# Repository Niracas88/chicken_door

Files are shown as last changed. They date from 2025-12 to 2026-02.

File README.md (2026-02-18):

# LoRa Chicken Door – Arduino + ESP32 WROOM32D + Home Assistant

Dit project bestaat uit twee onderdelen:

1. **Arduino UNO + RFM95W (LoRa-zender/ontvanger)**
2. **ESP32 WROOM32D + RFM95W (LoRa-brug naar Home Assistant via ESPHome)**

Samen vormen ze een draadloze, betrouwbare oplossing om een kippenluik automatisch te openen/sluiten op basis van lichtsterkte, met statusrapportering, remote instellingen en diagnostiek.
https://app.cirkitdesigner.com/project/e5ca5108-8e1d-4cd1-b3eb-05e4a613478f

---

## 📡 Overzicht van de werking

### Arduino-zijde
- Stuurt een motor die het kippenluik opent/sluit.
- Leest sensoren:
  - LDR lichtsensor  
  - Bovenste en onderste reedcontacten  
- Bepaalt automatisch:
  - **OPEN / CLOSED / MOVING / ERROR**  
- Verzendt periodiek een **JSON-statuspakket** via LoRa:
```json
{
  "light": 512,
  "threshold": 600,
  "door": "OPEN",
  "reedTop": 0,
  "reedBottom": 1
}

###📡 LoRa-commando’s**
Verwerkt inkomende LoRa-commando’s:

'T' + value → stel nieuwe lichtdrempel in

'S' → zend status terug

### 🛰 ESP32 LoRa Bridge (ESPHome)
De ESP32 ontvangt LoRa-berichten van de Arduino en publiceert die als entiteiten in Home Assistant:

Lichtwaarde
Drempelwaarde
LoRa RSSI en SNR
Reed-statussen
Luikstatus
Timestamps van RX/TX

Via Home Assistant kun je:

De lichtdrempel instellen (0–255, LoRa-schaal)

Handmatig een statusrequest naar de Arduino sturen

De ESP32 gebruikt een aangepaste sx127x driver via:

external_components:
  - source: github://pr#7490
    components: [ sx127x ]

### 🔧 Hardwarepinnen
Arduino UNO → RFM95W
Signaal	Pin
NSS	7
RST	6
DIO0	3
MOSI	11
MISO	12
SCK	13
ESP32 WROOM32D → RFM95W
Signaal	GPIO
NSS	5
RST	14
DIO0	26
MOSI	23
MISO	19
SCK	18

### 🧱 Dependencies
Arduino
LoRa library
EEPROM (standaard)
SPI (standaard)
ESPHome
ESPHome 2025.10.0 of recenter
Externe sx127x component via PR
Home Assistant (optioneel maar aanbevolen)

### 🧪 Testen

Start de Arduino → zou LoRa gereed moeten melden.
Start de ESP32 → ESPHome-console moet RX-pakketten tonen.
In Home Assistant verschijnen automatisch:
lichtsensor
drempel
reed-statussen
luikstatus
Verander de drempel → ESP32 verstuurt 'T'-pakket → Arduino past waarde aan.

### 📁 Bestanden

/kippenluik_v4_LoRa_def.ino
/esp32-wroom32D-LoRa_def.yaml
/README.md (dit document)

### 📜 Licentie
Vrij te gebruiken en aan te passen voor niet-commerciële projecten.

###💬 Contact / Issues

Open een GitHub issue bij fouten, suggesties of vragen.
Laat het weten als je ook een **GitHub badge header**, **screenshots-sectie**, of een **diagram van de L

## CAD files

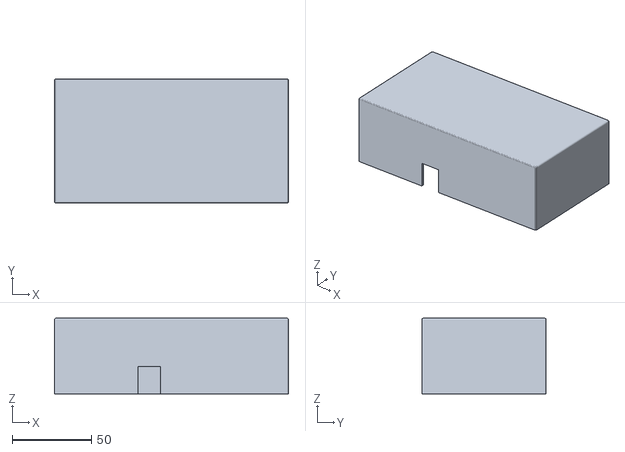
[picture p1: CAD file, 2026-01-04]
Arduino chicken coop box_lid.stl
147.4 x 78.4 x 47.7

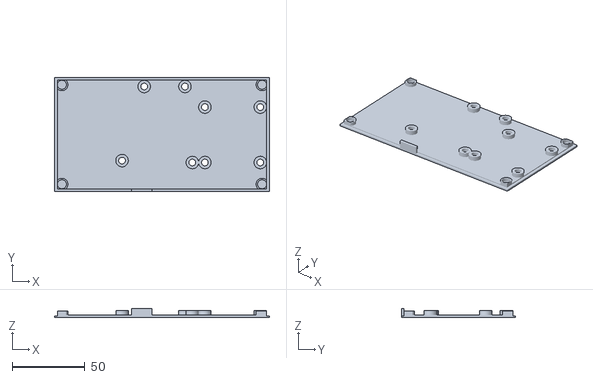
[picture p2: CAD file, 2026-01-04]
Arduino chicken coop box_bottom.stl
147.4 x 78.4 x 6.50

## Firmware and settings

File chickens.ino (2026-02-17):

#include <Arduino.h>
#include <EEPROM.h>

// ---------- Types (MOET bovenaan) ----------
typedef struct {
  bool top;
  bool bottom;
} Reeds;

// ---------- Forward declarations (veilig op Arduino IDE) ----------
bool reedRaw(int pin);
bool reedStable(int pin, unsigned long ms = 30);
Reeds readReeds();
void syncStateFromReeds(const Reeds& r);
void printStatus(int lightValue, const Reeds& r);
void handleSerial();
void calibrate();
bool moveTo(bool toOpen);
void updateLightMode(int lightValue);
bool motorActive = false;


// =====================================================
// MINIMALE, ROBUUSTE KIPPENLUIK-CODE (zonder LoRa)
// =====================================================

// -----------------------------
// Pinconfig
// -----------------------------
const int ENA = 10, IN1 = 9, IN2 = 8;
const int reedTop = 2, reedBottom = 4, LDRpin = A0;
const uint8_t PWM_SPEED = 200;

// -----------------------------
// EEPROM adressen
// -----------------------------
const int EEPROM_ADDR_THRESHOLD = 0;
const int EEPROM_ADDR_OPEN_MS   = 4;
const int EEPROM_ADDR_CLOSE_MS  = 8;

// -----------------------------
// Lichtdrempel
// -----------------------------
const int LIGHT_DEFAULT = 500;
int lightThreshold = LIGHT_DEFAULT;

// Hysterese + stabiliteit
const int LIGHT_HYST = 30;
const unsigned long LIGHT_STABLE_MS = 15000UL;

// -----------------------------
// Timeouts
// -----------------------------
const unsigned long DEFAULT_OPEN_MS  = 10000UL;
const unsigned long DEFAULT_CLOSE_MS = 10000UL;
const unsigned long MIN_TIMEOUT_MS   = 100000UL;
const unsigned long MAX_TIMEOUT_MS   = 100000UL;

const float         CAL_MARGIN_FACTOR = 1.25f;
const unsigned long CAL_MARGIN_MS     = 1000UL;

unsigned long maxOpenTime  = DEFAULT_OPEN_MS;
unsigned long maxCloseTime = DEFAULT_CLOSE_MS;

// -----------------------------
// State
// -----------------------------
enum DoorState { UNKNOWN, OPEN, CLOSED, MOVING_UP, MOVING_DOWN, ERROR_STATE };
DoorState state = UNKNOWN;

// -----------------------------
// Motor helpers
// -----------------------------
void motorStop() {
  analogWrite(ENA, 0);
  digitalWrite(IN1, LOW);
  digitalWrite(IN2, LOW);
  motorActive = false;

}
void motorUp() {
  analogWrite(ENA, PWM_SPEED);
  digitalWrite(IN1, HIGH);
  digitalWrite(IN2, LOW);
  motorActive = true;

}
void motorDown() {
  analogWrite(ENA, PWM_SPEED);
  digitalWrite(IN1, LOW);
  digitalWrite(IN2, HIGH);
  motorActive = true;

}

// -----------------------------
// Reed helpers
// -----------------------------
bool reedRaw(int pin) { return digitalRead(pin) == LOW; }

bool reedStable(int pin, unsigned long ms) {
  bool v = reedRaw(pin);
  unsigned long t0 = millis();
  while (millis() - t0 < ms) {
    bool v2 = reedRaw(pin);
    if (v2 != v) { v = v2; t0 = millis(); }
  }
  return v;
}

Reeds readReeds() {
  Reeds r;
  r.top = reedStable(reedTop, 30);
  r.bottom = reedStable(reedBottom, 30);
  return r;
}

// -----------------------------
// EEPROM load/save
// -----------------------------
unsigned long clampTimeout(unsigned long t) {
  if (t < MIN_TIMEOUT_MS) return MIN_TIMEOUT_MS;
  if (t > MAX_TIMEOUT_MS) return MAX_TIMEOUT_MS;
  return t;
}

void saveThreshold(int v) {
  v = constrain(v, 0, 1023);
  EEPROM.put(EEPROM_ADDR_THRESHOLD, v);
  lightThreshold = v;
  Serial.print("Threshold saved: "); Serial.println(lightThreshold);
}

void saveTimes(unsigned long openMs, unsigned long closeMs) {
  openMs = clampTimeout(openMs);
  closeMs = clampTimeout(closeMs);
  EEPROM.put(EEPROM_ADDR_OPEN_MS, openMs);
  EEPROM.put(EEPROM_ADDR_CLOSE_MS, closeMs);
  maxOpenTime = openMs;
  maxCloseTime = closeMs;
  Serial.print("Times saved: open="); Serial.print(maxOpenTime);
  Serial.print(" close="); Serial.println(maxCloseTime);
}

void loadConfig() {
  int thr;
  EEPROM.get(EEPROM_ADDR_THRESHOLD, thr);
  if (thr < 0 || thr > 1023) thr = LIGHT_DEFAULT;
  lightThreshold = thr;

  EEPROM.get(EEPROM_ADDR_OPEN_MS, maxOpenTime);
  EEPROM.get(EEPROM_ADDR_CLOSE_MS, maxCloseTime);

  if (maxOpenTime == 0 || maxOpenTime > 0xFFFFFFUL) maxOpenTime = DEFAULT_OPEN_MS;
  if (maxCloseTime == 0 || maxCloseTime > 0xFFFFFFUL) maxCloseTime = DEFAULT_CLOSE_MS;

  maxOpenTime = clampTimeout(maxOpenTime);
  maxCloseTime = clampTimeout(maxCloseTime);
}

// -----------------------------
// Status / state sync
// -----------------------------
const char* stateStr(DoorState s) {
  switch (s) {
    case OPEN: return "OPEN";
    case CLOSED: return "CLOSED";
    case MOVING_UP: return "MOVING_UP";
    case MOVING_DOWN: return "MOVING_DOWN";
    case ERROR_STATE: return "ERROR";
    default: return "UNKNOWN";
  }
}

void syncStateFromReeds(const Reeds& r) {
  if (r.top && !r.bottom) state = OPEN;
  else if (r.bottom && !r.top) state = CLOSED;
  else if (r.top && r.bottom) state = ERROR_STATE;
}

void printStatus(int lightValue, const Reeds& r) {
  Serial.print("Light="); Serial.print(lightValue);
  Serial.print(" Thr="); Serial.print(lightThreshold);
  Serial.print(" Top="); Serial.print(r.top ? "1" : "0");
  Serial.print(" Bot="); Serial.print(r.bottom ? "1" : "0");
  Serial.print(" State="); Serial.print(stateStr(state));
  Serial.print(" Motor=");
  Serial.print(motorActive ? "ON" : "OFF");
  Serial.print(" Topen="); Serial.print(maxOpenTime);
  Serial.print(" Tclose="); Serial.println(maxCloseTime);
}

// -----------------------------
// Movement with timeout
// -----------------------------
bool moveTo(bool toOpen) {
  unsigned long start = millis();
  unsigned long limit = toOpen ? maxOpenTime : maxCloseTime;
  int stopPin = toOpen ? reedTop : reedBottom;

  state = toOpen ? MOVING_UP : MOVING_DOWN;
  if (toOpen) motorUp(); else motorDown();

  while (millis() - start < limit) {
    if (reedStable(stopPin, 30)) {
      motorStop();
      state = toOpen ? OPEN : CLOSED;
      return true;
    }
    delay(10);
  }

  motorStop();
  state = ERROR_STATE;
  return false;
}

// -----------------------------
// Light decision
// -----------------------------
enum LightMode { LM_UNKNOWN, LM_DAY, LM_NIGHT };
LightMode lightMode = LM_UNKNOWN;
LightMode candidate = LM_UNKNOWN;
unsigned long candidateStart = 0;

void updateLightMode(int lightValue) {
  int openTh  = lightThreshold + LIGHT_HYST;
  int closeTh = lightThreshold - LIGHT_HYST;

  LightMode now;
  if (lightValue > openTh) now = LM_DAY;
  else if (lightValue < closeTh) now = LM_NIGHT;
  else now = LM_UNKNOWN;

  if (now == LM_UNKNOWN) {
    candidate = LM_UNKNOWN;
    candidateStart = 0;
    return;
  }

  if (now != candidate) {
    candidate = now;
    candidateStart = millis();
    return;
  }

  if (candidateStart && (millis() - candidateStart >= LIGHT_STABLE_MS)) {
    lightMode = candidate;
    candidate = LM_UNKNOWN;
    candidateStart = 0;
  }
}

// -----------------------------
// Calibration
// -----------------------------
void calibrate() {
  Serial.println("CAL: start");
  const unsigned long CAL_BACKSTOP = 100000UL;

  Serial.println("CAL: homing down...");
  motorDown();
  unsigned long t0 = millis();
  while (!reedStable(reedBottom, 30)) {
    if (millis() - t0 > CAL_BACKSTOP) {
      motorStop();
      Serial.println("CAL ERROR: bottom reed not reached (homing).");
      state = ERROR_STATE;
      return;
    }
    delay(10);
  }
  motorStop();
  state = CLOSED;
  delay(800);

  Serial.println("CAL: measuring open...");
  motorUp();
  t0 = millis();
  while (!reedStable(reedTop, 30)) {
    if (millis() - t0 > CAL_BACKSTOP) {
      motorStop();
      Serial.println("CAL ERROR: top reed not reached.");
      state = ERROR_STATE;
      return;
    }
    delay(10);
  }
  unsigned long openDur = millis() - t0;
  motorStop();
  state = OPEN;
  Serial.print("CAL: openDur="); Serial.println(openDur);
  delay(800);

  Serial.println("CAL: measuring close...");
  motorDown();
  t0 = millis();
  while (!reedStable(reedBottom, 30)) {
    if (millis() - t0 > CAL_BACKSTOP) {
      motorStop();
      Serial.println("CAL ERROR: bottom reed not reached.");
      state = ERROR_STATE;
      return;
    }
    delay(10);
  }
  unsigned long closeDur = millis() - t0;
  motorStop();
  state = CLOSED;
  Serial.print("CAL: closeDur="); Serial.println(closeDur);

  unsigned long newOpen  = (unsigned long)(openDur  * CAL_MARGIN_FACTOR) + CAL_MARGIN_MS;
  unsigned long newClose = (unsigned long)(closeDur * CAL_MARGIN_FACTOR) + CAL_MARGIN_MS;
  saveTimes(newOpen, newClose);

  Serial.println("CAL: done");
}

// -----------------------------
// Serial commands
// -----------------------------
void handleSerial() {
  if (!Serial.available()) return;

  char line[32];
  int len = Serial.readBytesUntil('\n', line, sizeof(line) - 1);
  if (len <= 0) return;

  if (line[len - 1] == '\r') len--;
  line[len] = '\0';

  char* p = line;
  while (*p == ' ' || *p == '\t') p++;

  if (strncmp(p, "T=", 2) == 0) {
    saveThreshold(atoi(p + 2));
  } else if (strcmp(p, "S?") == 0) {
    int lightValue = analogRead(LDRpin);
    Reeds r = readReeds();
    syncStateFromReeds(r);
    printStatus(lightValue, r);
  } else if (strcmp(p, "CAL") == 0) {
    calibrate();
  } else if (strcmp(p, "OPEN") == 0) {
    moveTo(true);
  } else if (strcmp(p, "CLOSE") == 0) {
    moveTo(false);
  } else {
    Serial.println("Cmd: T=xxx | S? | CAL | OPEN | CLOSE");
  }
}

// -----------------------------
// Setup
// -----------------------------
void setup() {
  pinMode(ENA, OUTPUT);
  pinMode(IN1, OUTPUT);
  pinMode(IN2, OUTPUT);
  pinMode(reedTop, INPUT_PULLUP);
  pinMode(reedBottom, INPUT_PULLUP);

  // Zorg dat motor nooit “zweeft” bij boot
  motorStop();

  Serial.begin(9600);
  delay(100);

  loadConfig();

  Serial.println("Minimal chicken door controller started.");
  Serial.print("Threshold="); Serial.print(lightThreshold);
  Serial.print("  OpenT="); Serial.print(maxOpenTime);
  Serial.print("  CloseT="); Serial.println(maxCloseTime);
  Serial.println("Cmd: T=xxx | S? | CAL | OPEN | CLOSE");

  Reeds r = readReeds();
  syncStateFromReeds(r);
  if (state == UNKNOWN) {
    Serial.println("Homing down at boot...");
    moveTo(false);
  }
}

// -----------------------------
// Main loop
// -----------------------------
void loop() {
  handleSerial();

  int lightValue = analogRead(LDRpin);
  Reeds r = readReeds();

  syncStateFromReeds(r);
  updateLightMode(lightValue);

  if (state != ERROR_STATE) {
    if (lightMode == LM_DAY) {
      if (state != OPEN) moveTo(true);
    } else if (lightMode == LM_NIGHT) {
      if (state != CLOSED) moveTo(false);
    }
  }

  static unsigned long lastStatus = 0;
  if (millis() - lastStatus > 1000UL) {
    printStatus(lightValue, r);
    lastStatus = millis();
  }

  delay(200);
}

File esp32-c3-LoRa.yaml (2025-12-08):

esphome:
  name: esp32-wroom-wifi-debug
  friendly_name: ESP32 WROOM WiFi Debug Minimal

esp32:
  board: esp32dev
  framework:
    type: arduino

logger:
  level: DEBUG

wifi:
  ssid: "BvdBHome"
  password: "^qsW6ES74JSm24!JTxOpW3!6WLIal@"

  manual_ip:
    static_ip: 192.168.0.50
    gateway: 192.168.0.1
    subnet: 255.255.255.0

  ap:
    ssid: "esp32c3_lora_fallback"
    password: "12345678"

captive_portal:

api:
ota:
  platform: esphome

web_server:
  port: 80

# SPI-bus naar RFM95W (ESP32-C3)
spi:
  clk_pin: GPIO4
  mosi_pin: GPIO6
  miso_pin: GPIO5

# SX127x (RFM95W) LoRa-config
sx127x:
  id: lora_radio
  cs_pin: GPIO7
  rst_pin: GPIO2
  dio0_pin: GPIO3

  frequency: 868000000      # 868 MHz
  modulation: LORA
  bandwidth: 125_0kHz
  spreading_factor: 7
  coding_rate: CR_4_5
  sync_value: 0x12          # zelfde als Arduino-LoRa
  crc_enable: false
  preamble_size: 8
  rx_start: true

  # Wanneer een JSON-pakket van de Arduino binnenkomt
  on_packet:
    then:
      - lambda: |-
          // x = std::vector<uint8_t> payload
          ESP_LOGD("lora", "raw packet: %s", format_hex(x).c_str());

          std::string s(x.begin(), x.end());
          ESP_LOGD("lora", "text packet: %s", s.c_str());
          ESP_LOGD("lora", "rssi: %.2f dB, snr: %.2f dB", rssi, snr);

          // eenvoudige JSON-parser voor payload:
          // {"light":512,"threshold":600,"door":"OPEN","reedTop":0,"reedBottom":1}

          auto get_int = [&](const char *key) -> int {
            std::string k(key);
            size_t pos = s.find(k);
            if (pos == std::string::npos) return -1;
            pos += k.size();
            size_t end = s.find_first_of(",}", pos);
            if (end == std::string::npos) end = s.size();
            std::string num = s.substr(pos, end - pos);
            return atoi(num.c_str());
          };

          auto get_str = [&](const char *key) -> std::string {
            std::string k(key);
            size_t pos = s.find(k);
            if (pos == std::string::npos) return "";
            pos += k.size();
            size_t end = s.find('"', pos);
            if (end == std::string::npos) return "";
            return s.substr(pos, end - pos);
          };

          int light_val      = get_int("\"light\":");
          int threshold_val  = get_int("\"threshold\":");
          int reed_top_val   = get_int("\"reedTop\":");
          int reed_bottom_val= get_int("\"reedBottom\":");
          std::string door   = get_str("\"door\":\"");

          if (light_val >= 0) {
            id(lora_light).publish_state(light_val);
          }
          if (threshold_val >= 0) {
            id(lora_threshold_rx).publish_state(threshold_val);
          }

          if (!door.empty()) {
            id(lora_door_state).publish_state(door.c_str());
          }

          if (reed_top_val == 0 || reed_top_val == 1) {
            id(lora_reed_top).publish_state(reed_top_val == 1);
          }

          if (reed_bottom_val == 0 || reed_bottom_val == 1) {
            id(lora_reed_bottom).publish_state(reed_bottom_val == 1);
          }

          // RSSI en SNR ook als sensoren publiceren
          id(lora_rssi).publish_state(rssi);
          id(lora_snr).publish_state(snr);
          
          // Update last received timestamp
          id(lora_last_rx).publish_state(id(esptime).now().timestamp);

# Sensors die in Home Assistant zichtbaar worden
sensor:
  - platform: template
    id: lora_light
    name: "Kippenluik lichtwaarde"
    unit_of_measurement: ""
    icon: "mdi:brightness-5"
    accuracy_decimals: 0
    update_interval: never
    state_class: measurement

  - platform: template
    id: lora_threshold_rx
    name: "Kippenluik drempel (0-1023)"
    unit_of_measurement: ""
    icon: "mdi:tune-variant"
    accuracy_decimals: 0
    update_interval: never
    state_class: measurement

  - platform: template
    id: lora_rssi
    name: "LoRa RSSI"
    unit_of_measurement: "dBm"
    icon: "mdi:signal-cellular-3"
    accuracy_decimals: 1
    update_interval: never
    device_class: signal_strength
    state_class: measurement
    entity_category: diagnostic

  - platform: template
    id: lora_snr
    name: "LoRa SNR"
    unit_of_measurement: "dB"
    icon: "mdi:waveform"
    accuracy_decimals: 1
    update_interval: never
    state_class: measurement
    entity_category: diagnostic

  - platform: template
    id: lora_last_rx
    name: "LoRa laatste ontvangst"
    device_class: timestamp
    entity_category: diagnostic
    update_interval: never

  # WiFi signal strength for diagnostics
  - platform: wifi_signal
    name: "WiFi signaalsterkte"
    update_interval: 60s
    entity_category: diagnostic
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

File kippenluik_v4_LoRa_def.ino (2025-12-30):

#include <Arduino.h>
#include <EEPROM.h>
#include <SPI.h>
#include <LoRa.h>

// -----------------------------
// Pinconfig kippenluik
// -----------------------------
const int ENA = 10, IN1 = 9, IN2 = 8;
const int reedTop = 2, reedBottom = 4, LDRpin = A0;
const int PWM_SPEED = 200;

const int EEPROM_ADDR_THRESHOLD = 0;
const int EEPROM_ADDR_OPEN      = 4;
const int EEPROM_ADDR_CLOSE     = 8;
const int LIGHT_DEFAULT         = 500;

int lightThreshold = LIGHT_DEFAULT;
unsigned long maxOpenTime  = 10000;
unsigned long maxCloseTime = 10000;

enum DoorState { UNKNOWN, OPEN, CLOSED, MOVING_UP, MOVING_DOWN, ERROR_STATE };
DoorState state = UNKNOWN;
unsigned long lastPrint = 0;

// -----------------------------
// LoRa-config
// -----------------------------
const long LORA_FREQUENCY = 868E6;   // 868 MHz (EU)
const byte LORA_SYNC_WORD  = 0x12;   // private sync word

// RFM95W-pinnen op de Arduino
const int LORA_NSS  = 7;
const int LORA_RST  = 6;
const int LORA_DIO0 = 3;

// SPI-pinnen UNO (vast):
// SCK  = 13
// MISO = 12
// MOSI = 11

unsigned long lastLoraSend = 0;
const unsigned long LORA_INTERVAL = 5000; // elke 5 s een pakket sturen
bool loraOk = false;

// -----------------------------
// Motorhelpers
// -----------------------------
void motorStop() {
  analogWrite(ENA, 0);
  digitalWrite(IN1, LOW);
  digitalWrite(IN2, LOW);
}

void motorUp() {
  analogWrite(ENA, PWM_SPEED);
  digitalWrite(IN1, HIGH);
  digitalWrite(IN2, LOW);
}

void motorDown() {
  analogWrite(ENA, PWM_SPEED);
  digitalWrite(IN1, LOW);
  digitalWrite(IN2, HIGH);
}

// -----------------------------
// Reed helpers
// -----------------------------
bool reedActiveRaw(int pin) {
  // LOW = actief bij INPUT_PULLUP
  return digitalRead(pin) == LOW;
}

bool reedActiveStable(int pin, unsigned long ms = 30) {
  bool first = reedActiveRaw(pin);
  unsigned long t0 = millis();
  while (millis() - t0 < ms) {
    if (reedActiveRaw(pin) != first) {
      first = reedActiveRaw(pin);
      t0 = millis();
    }
  }
  return first;
}

// -----------------------------
// EEPROM
// -----------------------------
void saveThreshold(int val) {
  val = constrain(val, 0, 1023);
  EEPROM.put(EEPROM_ADDR_THRESHOLD, val);
  lightThreshold = val;
  Serial.print("Drempel opgeslagen (EEPROM) = ");
  Serial.println(lightThreshold);
}

void loadConfig() {
  int val;
  EEPROM.get(EEPROM_ADDR_THRESHOLD, val);
  if (val < 0 || val > 1023) val = LIGHT_DEFAULT;
  lightThreshold = val;

  EEPROM.get(EEPROM_ADDR_OPEN, maxOpenTime);
  EEPROM.get(EEPROM_ADDR_CLOSE, maxCloseTime);
  if (maxOpenTime == 0 || maxCloseTime == 0) {
    maxOpenTime = maxCloseTime = 10000;
  }
}

// -----------------------------
// Statushelpers
// -----------------------------
const char* doorStateToString(DoorState s) {
  switch (s) {
    case OPEN:         return "OPEN";
    case CLOSED:       return "CLOSED";
    case MOVING_UP:    return "MOVING_UP";
    case MOVING_DOWN:  return "MOVING_DOWN";
    case ERROR_STATE:  return "ERROR";
    default:           return "UNKNOWN";
  }
}

void printStatus(int lightValue) {
  Serial.print("Licht=");      Serial.print(lightValue);
  Serial.print("  Drempel=");  Serial.print(lightThreshold);
  Serial.print("  Top=");
  Serial.print(reedActiveRaw(reedTop) ? "GESLOTEN" : "OPEN");
  Serial.print("  Bottom=");
  Serial.print(reedActiveRaw(reedBottom) ? "GESLOTEN" : "OPEN");
  Serial.print("  Luik=");
  Serial.println(doorStateToString(state));
}

// -----------------------------
// Beweging met failsafe
// -----------------------------
bool moveUntilReedOrTimeout(bool omhoog) {
  unsigned long start = millis();
  unsigned long limit = omhoog ? maxOpenTime : maxCloseTime;
  const char* actie   = omhoog ? "openen" : "sluiten";
  int stopPin         = omhoog ? reedTop : reedBottom;

  Serial.print("Actie: "); Serial.println(actie);
  if (omhoog) motorUp(); else motorDown();

  while (millis() - start < limit) {
    if (reedActiveStable(stopPin)) {
      motorStop();
      Serial.print("Reed gedetecteerd bij "); Serial.println(actie);
      return true;
    }
    delay(10);
  }

  motorStop();
  Serial.print("Tijdslimiet bereikt bij "); Serial.println(actie);
  state = ERROR_STATE;
  return false;
}

// -----------------------------
// Calibratie zonder harde tijdslimiet
// -----------------------------
void calibrateTimes() {
  Serial.println("Start automatische calibratie...");
  unsigned long t0, durClose = 0, durOpen = 0;

  // Eerst volledig sluiten
  if (!reedActiveStable(reedBottom)) {
    Serial.println("Sluiten tot onderste reed...");
    motorDown();
    t0 = millis();
    while (!reedActiveStable(reedBottom)) {
      if ((millis() - t0) % 1000 < 10) {
        Serial.print("DBG Top=");    Serial.print(reedActiveRaw(reedTop));
        Serial.print(" Bottom=");    Serial.println(reedActiveRaw(reedBottom));
      }
      delay(10);
    }
    durClose = millis() - t0;
    motorStop();
    Serial.print("Onderste reed bereikt na "); Serial.print(durClose); Serial.println(" ms.");
  } else {
    durClose = 0;
    Serial.println("Onderste reed was al actief bij start.");
  }

  delay(1000);

  // Beweging omhoog
  Serial.println("Beweging omhoog voor kalibratie...");
  t0 = millis();
  motorUp();
  while (!reedActiveStable(reedTop)) {
    if ((millis() - t0) % 1000 < 10) {
      Serial.print("DBG Top=");    Serial.print(reedActiveRaw(reedTop));
      Serial.print(" Bottom=");    Serial.println(reedActiveRaw(reedBottom));
    }
    delay(10);
  }
  durOpen = millis() - t0;
  motorStop();
  Serial.print("Bovenste reed bereikt na "); Serial.print(durOpen); Serial.println(" ms.");

  delay(1000);

  // Beweging omlaag
  Serial.println("Beweging omlaag voor kalibratie...");
  t0 = millis();
  motorDown();
  while (!reedActiveStable(reedBottom)) {
    if ((millis() - t0) % 1000 < 10) {
      Serial.print("DBG Top=");    Serial.print(reedActiveRaw(reedTop));
      Serial.print(" Bottom=");    Serial.println(reedActiveRaw(reedBottom));
    }
    delay(10);
  }
  durClose = millis() - t0;
  motorStop();
  Serial.print("Onderste reed opnieuw bereikt na "); Serial.print(durClose); Serial.println(" ms.");

  // Opslaan met 10% marge
  maxOpenTime  = (unsigned long)(durOpen  * 1.1);
  maxCloseTime = (unsigned long)(durClose * 1.1);
  EEPROM.put(EEPROM_ADDR_OPEN,  maxOpenTime);
  EEPROM.put(EEPROM_ADDR_CLOSE, maxCloseTime);

  Serial.print("Calibratie voltooid. Open=");  Serial.print(durOpen);
  Serial.print(" ms, Dicht=");                 Serial.print(durClose);
  Serial.println(" ms (met 10% marge).");
  state = CLOSED;
}
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

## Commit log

2025-10-21 GPT gesprek over arduino code voor kippenluik
2025-11-02 Add Arduino code for chicken coop door automation v3
    Implement Arduino-based control for a chicken coop door with light detection and reed switch feedback.
2025-12-05 Add ESP32-C3 LoRa configuration file
2025-12-05 Add LoRa sender functionality in Arduino sketch
2025-12-05 Add Arduino sketch for chicken coop door control
    This file implements an Arduino sketch for controlling a chicken coop door with motor control, light detection, and LoRa communication.
2025-12-05 Add LoRa sensors and binary sensor configurations
    Added sensors and binary sensors for LoRa integration.
2025-12-08 Add LoRa sensors and ESP32 status monitoring
    Added sensors for LoRa RSSI, SNR, last received and transmitted timestamps, and ESP32 status. Updated WiFi signal strength and added a button for manual status requests.
2025-12-08 Update ESPHome configuration for ESP32 board
2025-12-08 Modify ESP32 WROOM-32D LoRa configuration
    Updated configuration for ESP32 WROOM-32D, including changes to SSID, SPI bus pins, and added encryption key. Adjusted comments for clarity and enabled CRC.
2025-12-11 Add ESP32 LoRa configuration and sensors
2025-12-11 Refactor ESP32 config for Chicken RX/TX
    Updated ESP32 configuration for Chicken RX/TX. Enhanced logging and removed unnecessary WiFi manual IP settings.
2025-12-11 Expand README with ESP32 LoRa Bridge details
    Added detailed instructions for using the ESP32 LoRa Bridge with Arduino, including command processing, hardware pin connections, dependencies, testing procedures, and file structure.
2025-12-30 Document SPI pin assignments in the code
    Added comments for SPI pin assignments on UNO.
2025-12-30 Add LoRa debug functionality for Arduino
    This Arduino sketch implements a LoRa debug tool for RX sniffing and optional TX commands. It includes command handling for PING, status requests, and threshold settings.
2026-01-07 Add initial version of Arduino LoRa control code
2026-01-11 Modify timeout values and track motor state
    Updated timeout constants and added motorActive state tracking.
